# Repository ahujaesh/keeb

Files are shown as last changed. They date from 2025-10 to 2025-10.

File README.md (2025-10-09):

Eshaan's Split Keeb!

A seed studio rp2040 based ergonomic split keyboards to make essay writing slightly less boring! It has 50 keys (alphabet [26], numbers [10], ;,./ [4], two shifts [2], two ctrls [2], win key [1], two space keys [2], and two keys i plan to remap once the board comes in depending on what i fell like im missing), a built in USB hub, and a haptic motor!

PCB ([kicad](/keeb), [gerbers](/gerbers_final^2.zip)):
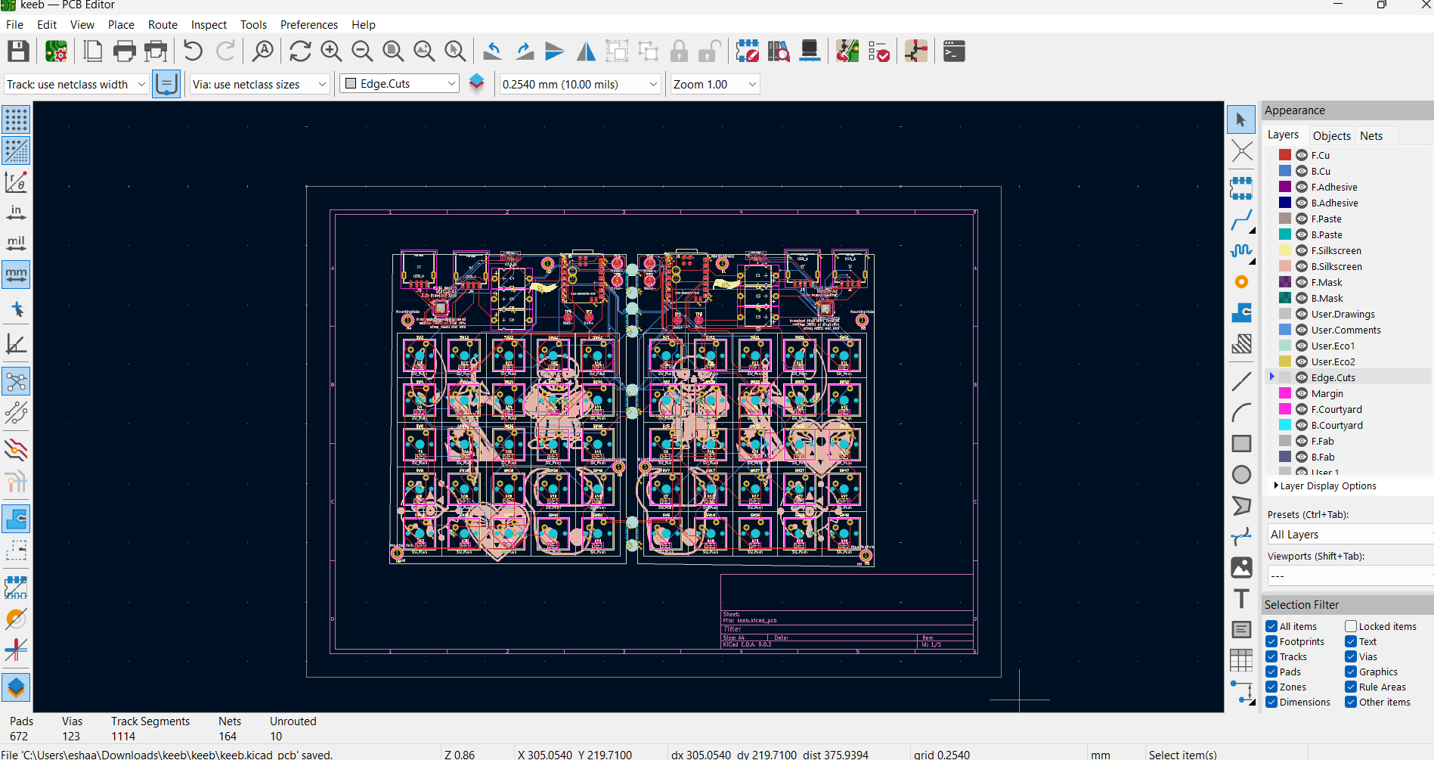
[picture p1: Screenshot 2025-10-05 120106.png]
pcb screenshot

CAD ([STEP file of assembly](/final_assembly.step), [top plate](/Top%20plate.step), [bottom plate](/Bottom%20plate.step)):
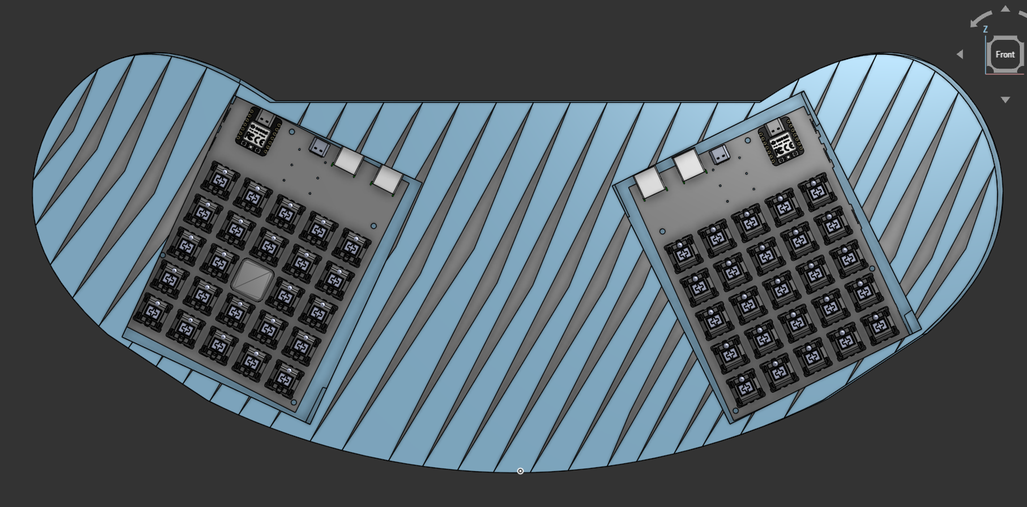
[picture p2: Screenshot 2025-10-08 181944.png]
cad screenshot

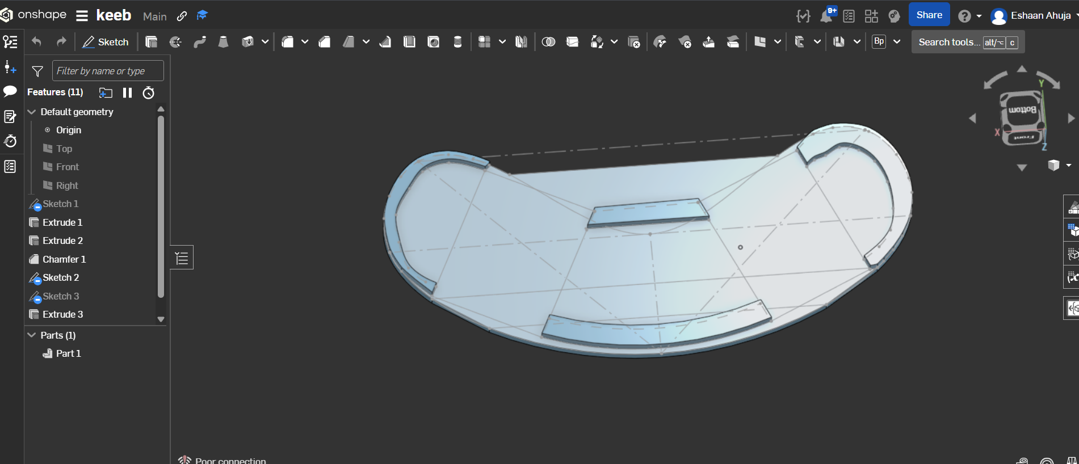
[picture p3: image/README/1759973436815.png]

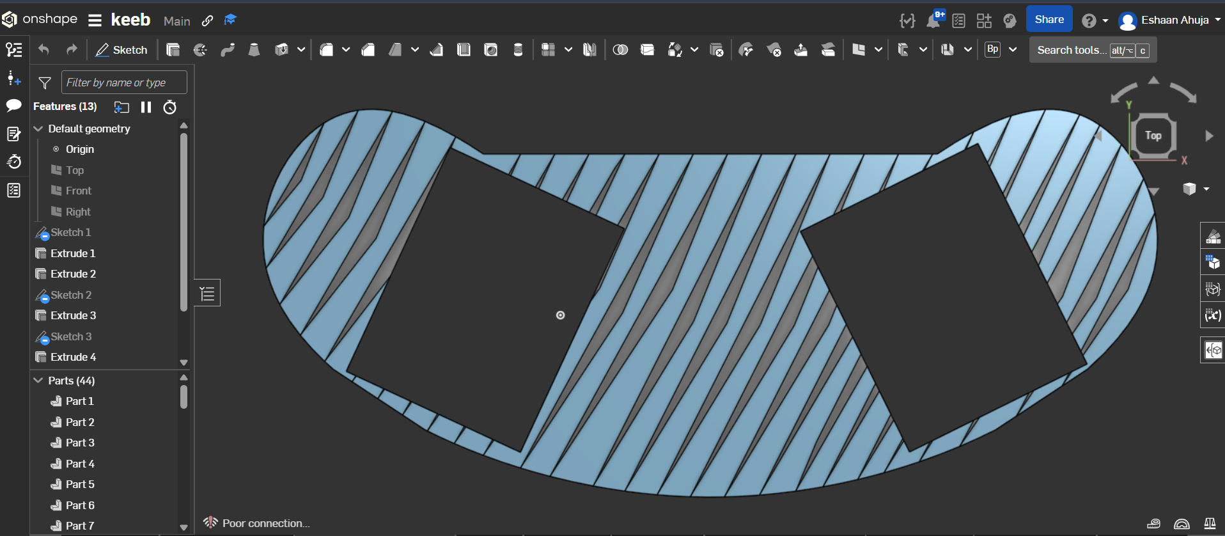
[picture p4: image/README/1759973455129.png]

Firmware [[left](/left.py), [right](/right.py)]: KMK (python), two files, one per board. Key matrix and one layer (for now, once i get the keeb i might add one more for funzies)
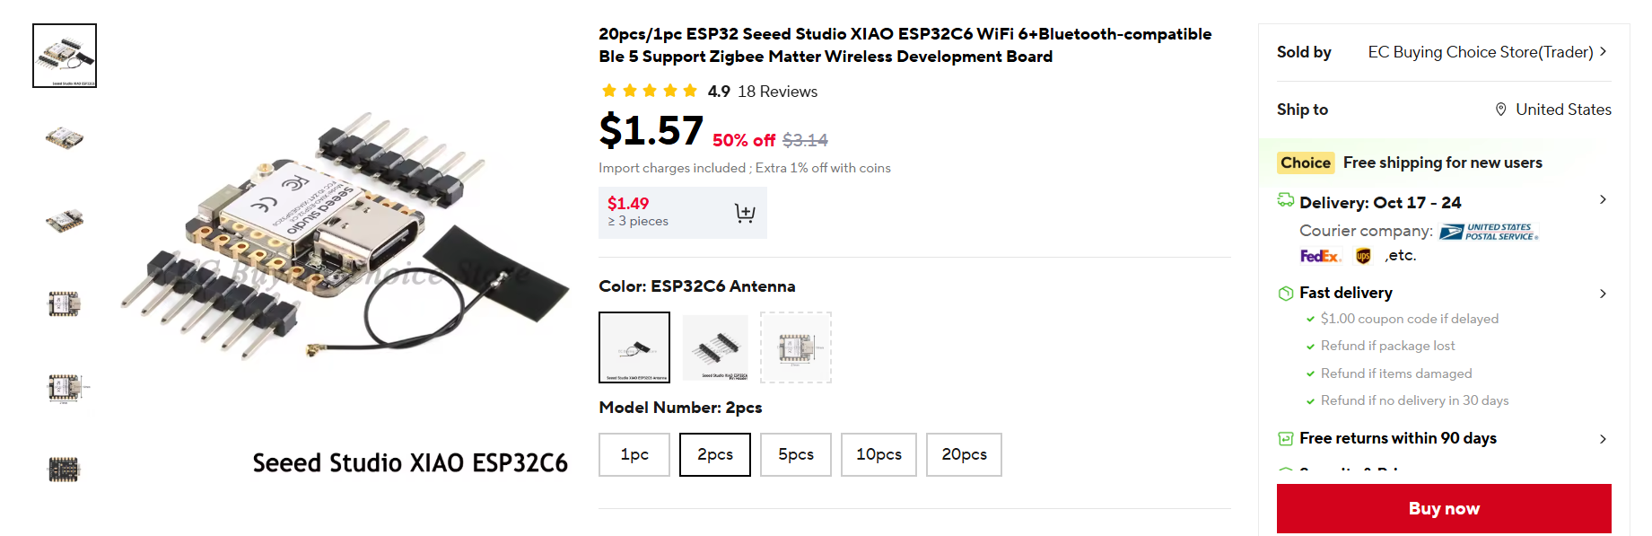
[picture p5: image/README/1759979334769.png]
Aliexpress screenshot 
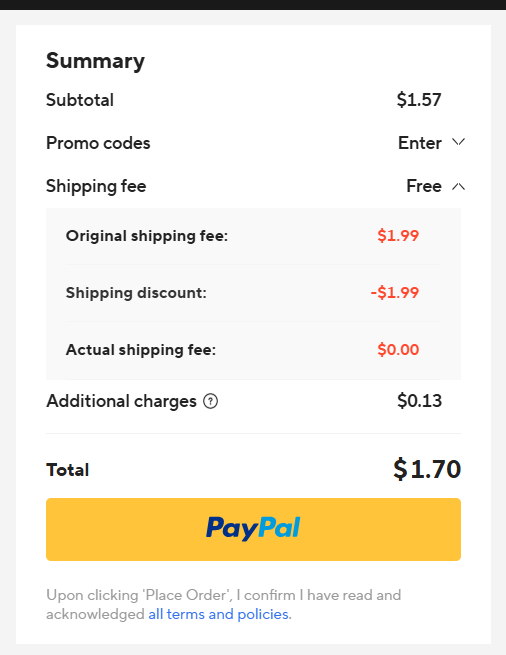
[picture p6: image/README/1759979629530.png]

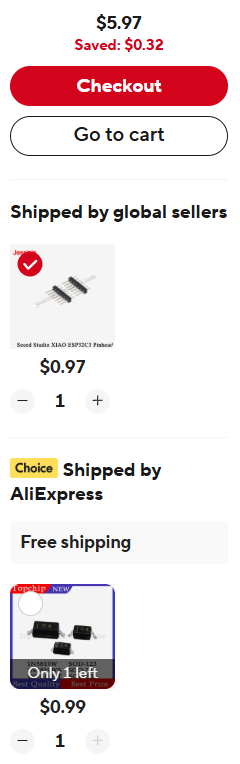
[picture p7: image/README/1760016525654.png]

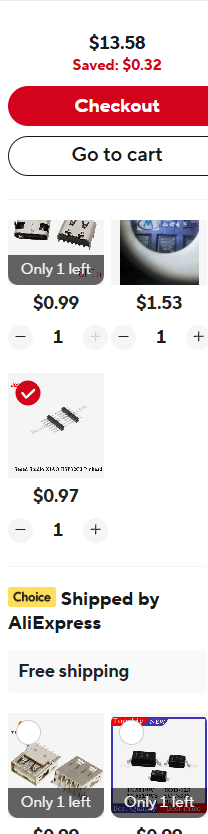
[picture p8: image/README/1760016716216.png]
aliexpress screenshot with everything: 
amazon switches screenshot

All for the low price of 54.73 USD :crying emoji:
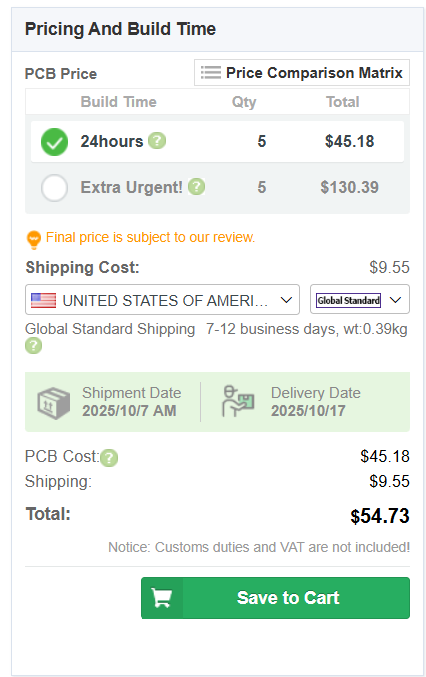
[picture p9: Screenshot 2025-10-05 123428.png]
pcbway quote


AND it has a built in USB hub for PIZZAZ

Using the USB2512_AEZG chip, I take an input of USBC and split it into two USBA ports (bc no laptop nowadays comes with USBA ports smh)
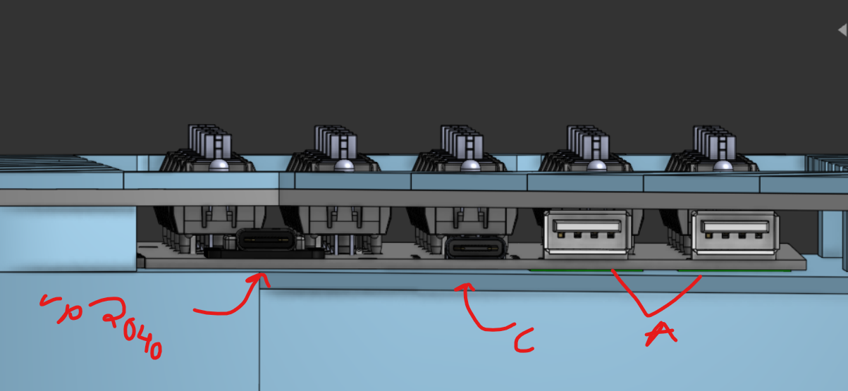
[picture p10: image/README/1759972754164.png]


This keyboard has a 5x5 matrix on both sides, positioned at a comfortable 27 degrees so that my wrists don't cramp up while typing! It uses MX switches (the cheapest ones I could find lmao) (not hot swappable unfortunately), and 3d printed keycaps (save hack club some money lmao)

Finally, it has a built in haptic motor soldered onto the pcb to provide a better typing experience :) I couldnt find a cad model but its a really small motor that sits under the USBA ports and gets attached to the test points on the side of the seed studio

Note: switches are soldered on, I am printing the top and bottom plate, as well as the keycaps. for more info, see the [BOM](/bom.csv)

I had a lot of fun playing with splines etc whilst doing this project! Thanks hack club for the opportunity

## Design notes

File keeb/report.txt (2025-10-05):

Plotted to 'C:\Users\eshaa\Downloads\keeb\keeb-F_Cu.gbr'.
Plotted to 'C:\Users\eshaa\Downloads\keeb\keeb-B_Cu.gbr'.
Plotted to 'C:\Users\eshaa\Downloads\keeb\keeb-F_Paste.gbr'.
Plotted to 'C:\Users\eshaa\Downloads\keeb\keeb-B_Paste.gbr'.
Plotted to 'C:\Users\eshaa\Downloads\keeb\keeb-F_Silkscreen.gbr'.
Plotted to 'C:\Users\eshaa\Downloads\keeb\keeb-B_Silkscreen.gbr'.
Plotted to 'C:\Users\eshaa\Downloads\keeb\keeb-F_Mask.gbr'.
Plotted to 'C:\Users\eshaa\Downloads\keeb\keeb-B_Mask.gbr'.
Plotted to 'C:\Users\eshaa\Downloads\keeb\keeb-Edge_Cuts.gbr'.
Created Gerber job file 'C:\Users\eshaa\Downloads\keeb\keeb-job.gbrjob'.
Info: Done.
Info: Done.

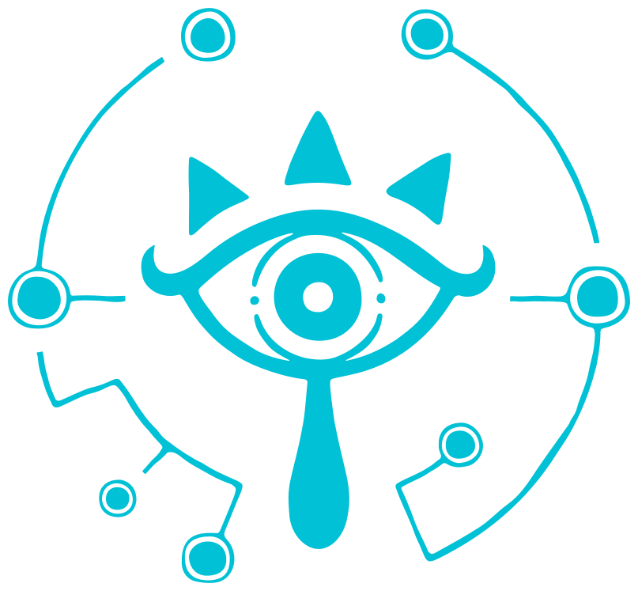
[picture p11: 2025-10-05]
images/Das_Shiekah_Auge_BoTW.webp

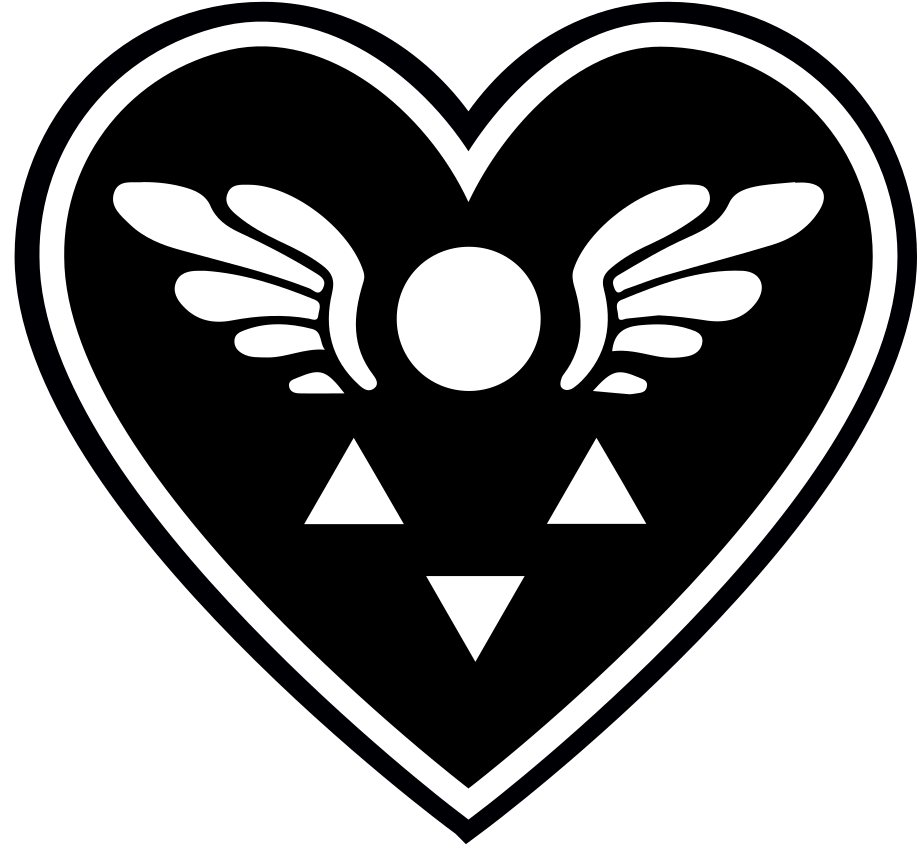
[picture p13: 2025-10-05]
images/v1180jzwulx11.png

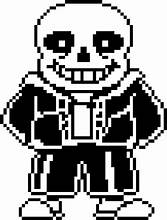
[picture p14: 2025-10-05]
images/OIP2.jpeg

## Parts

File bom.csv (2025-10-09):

name | costs (USD) | notes
pcb | 54.73 | see screenshot in readme
motors | 0 | for haptics and self sourced (i already have some)
seed studio xiao x2 (one per side) | 1.7 | see readme for screenshots from aliexpress
keycaps | 0 | 3d printed by me
switches | 25 | $5 per 10 = 25 for 50 keycaps; amazon
capacitors | 0 | self sourced (I already have them)
diodes | 5.97 | aliexpress shipping is expensive
usb2512aezg chip | 7 | to power the usb hub; see screenshot in readme; sourced from aliexpress
usba port x4 | 1 | see screenshot in readme; sourced from aliexpress
usbc port x2 | 1 | aliexpress
3d printed parts | 0 | I'm printing everything myself
TOTAL | 96.4 USD | thank you!

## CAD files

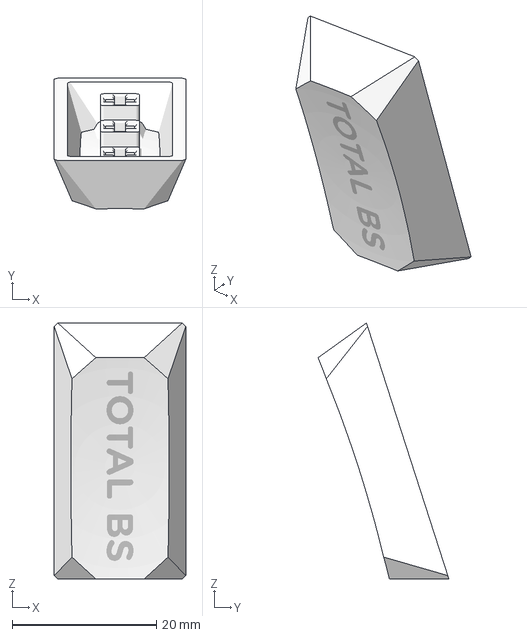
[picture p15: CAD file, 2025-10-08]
misc/complete-cherry-mx-stem-keycap-set-optimized-for-3d-printing-gem-profile-multi-material-model_files/2U_TOTALBS.3mf
18.2 x 18.1 x 35.5 mm

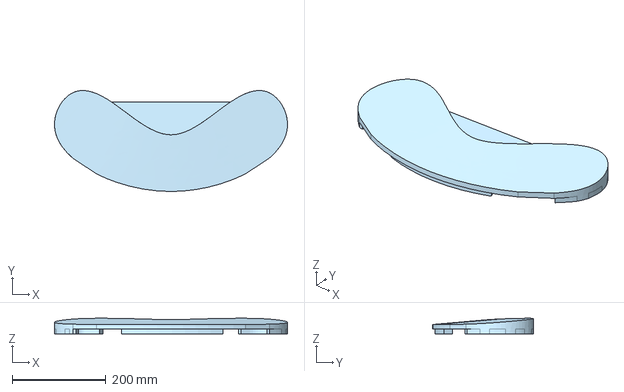
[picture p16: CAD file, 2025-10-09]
Bottom plate.step
498.1 x 215.9 x 33.3 mm

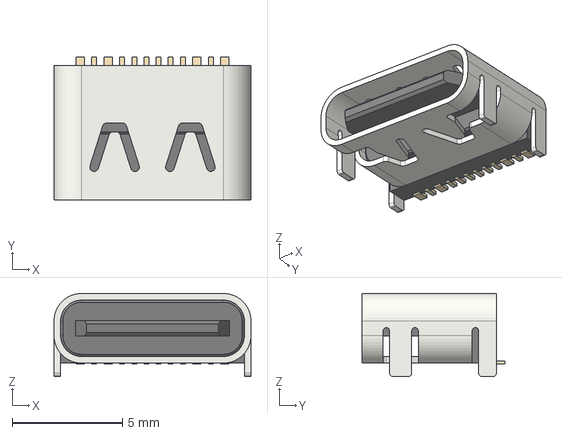
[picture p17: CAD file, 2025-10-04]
marbastlib-main/marbastlib-main/3dmodels/CON_TYPE-C-31-M-23.step
8.94 x 6.50 x 3.77 mm

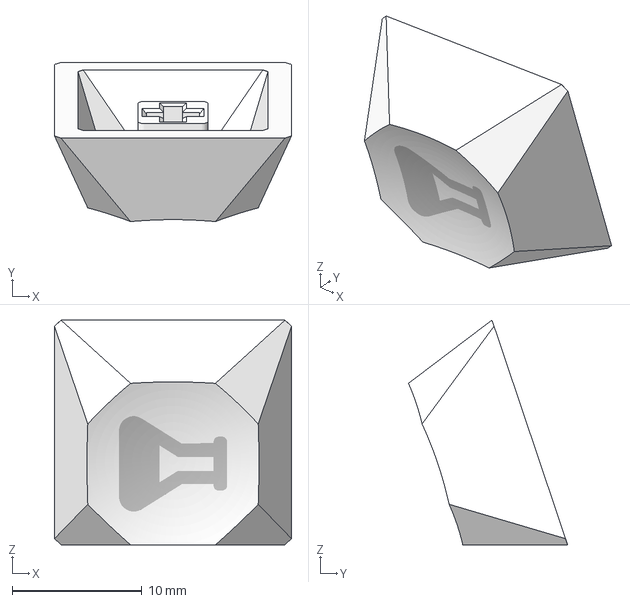
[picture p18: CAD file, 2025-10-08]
misc/complete-cherry-mx-stem-keycap-set-optimized-for-3d-printing-gem-profile-multi-material-model_files/flask.3mf
18.2 x 12.3 x 17.3 mm

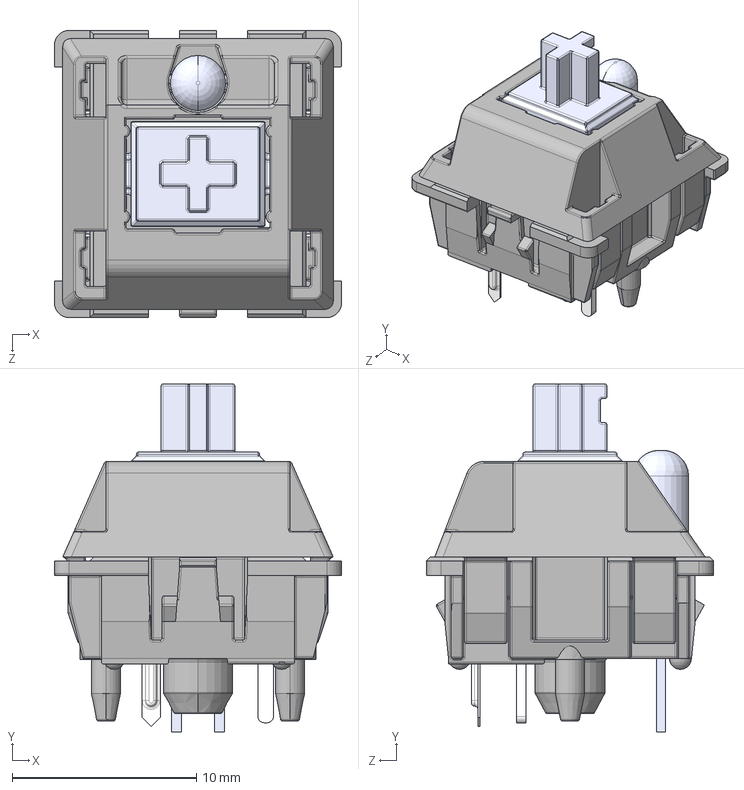
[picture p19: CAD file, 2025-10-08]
misc/MX .STEP
15.6 x 18.9 x 15.6 mm
MX 轴 按键′_ü___¨1
MX 轴 轴体áì_¨￠¨__
MX粣 拸簽LEDLEDLED
MX轴 轴体 底部 μ×2__默认_á2____è_
针脚___默认__è_

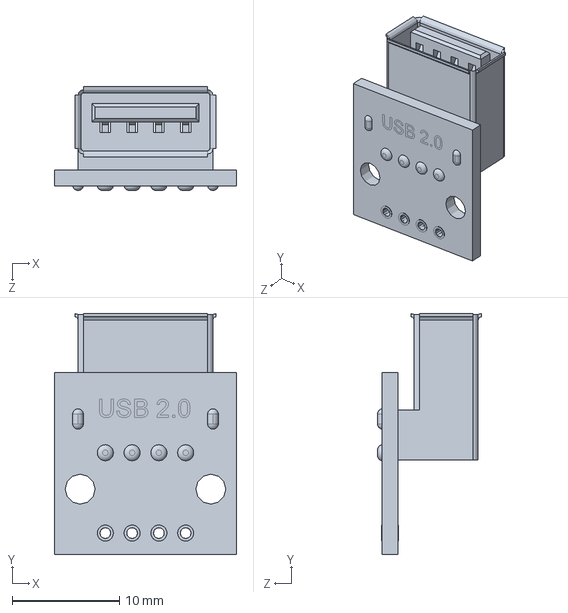
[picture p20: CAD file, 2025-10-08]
misc/usb-a-female-2.snapshot.1/модуль USB A.SLDPRT
17.0 x 22.5 x 9.70 mm

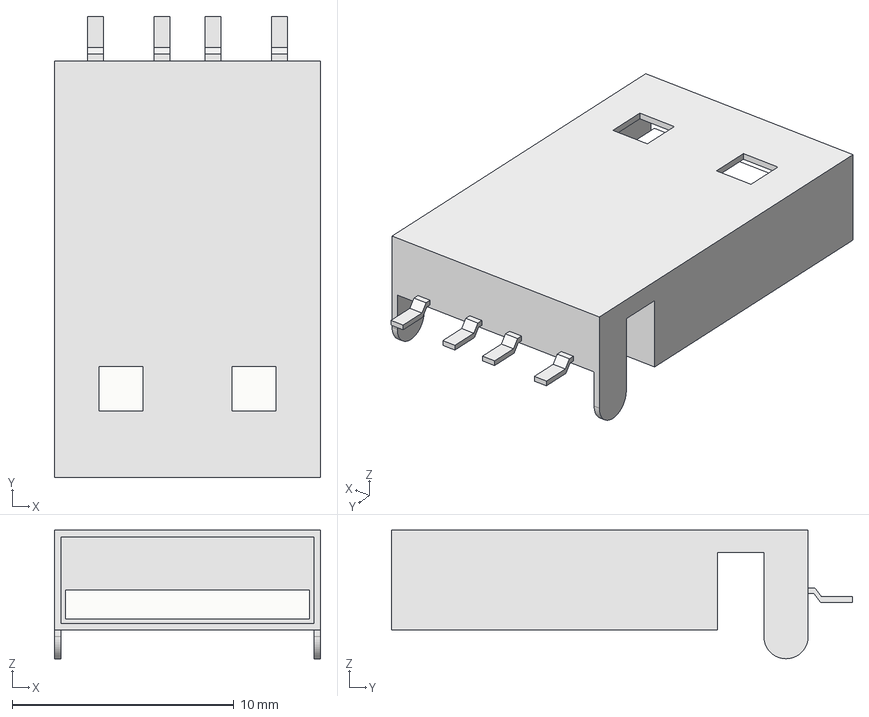
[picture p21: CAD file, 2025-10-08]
misc/usb-type-a-connector-2.snapshot.1/USB Type A.step
12.0 x 20.8 x 5.80 mm

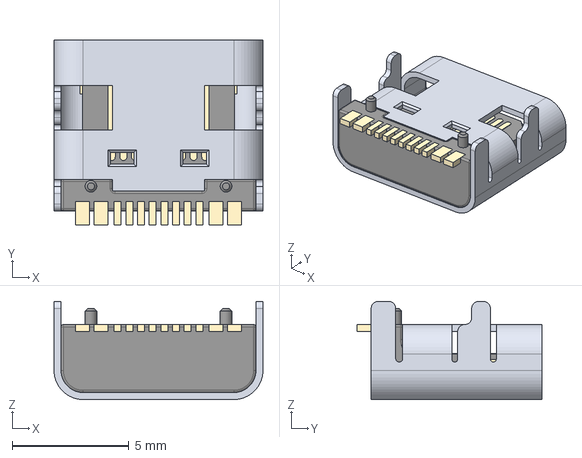
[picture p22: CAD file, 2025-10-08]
misc/usb-type-c-port-2.snapshot.1/USB Type C PoRT.step
8.94 x 7.90 x 4.20 mm

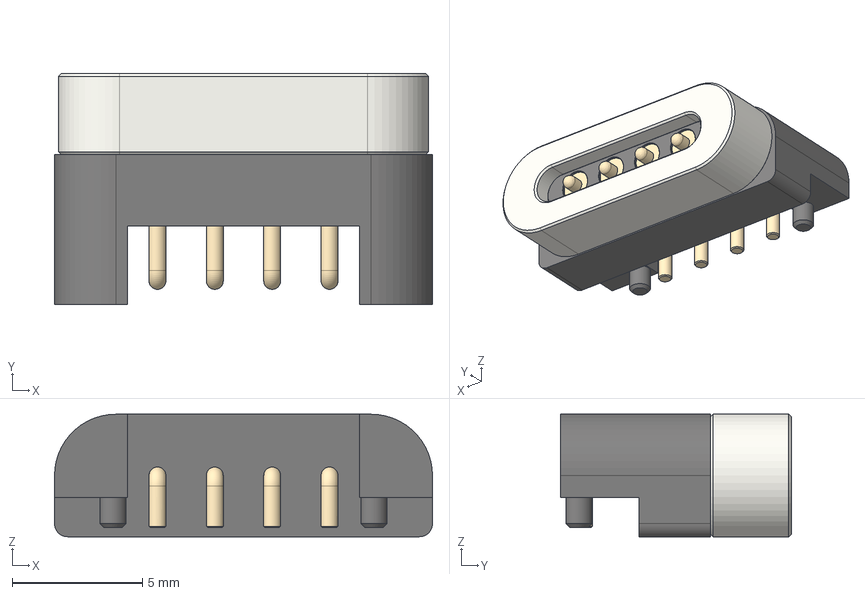
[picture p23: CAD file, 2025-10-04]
marbastlib-main/marbastlib-main/3dmodels/CON_HytePro_M411P_Receptacle_1x04.step
14.5 x 8.85 x 4.70 mm
Magnetic Connector Female - MiddlePart
Magnetic Connector Female-tip_Standard
Magnetic Connector Female v2 - MountingPart

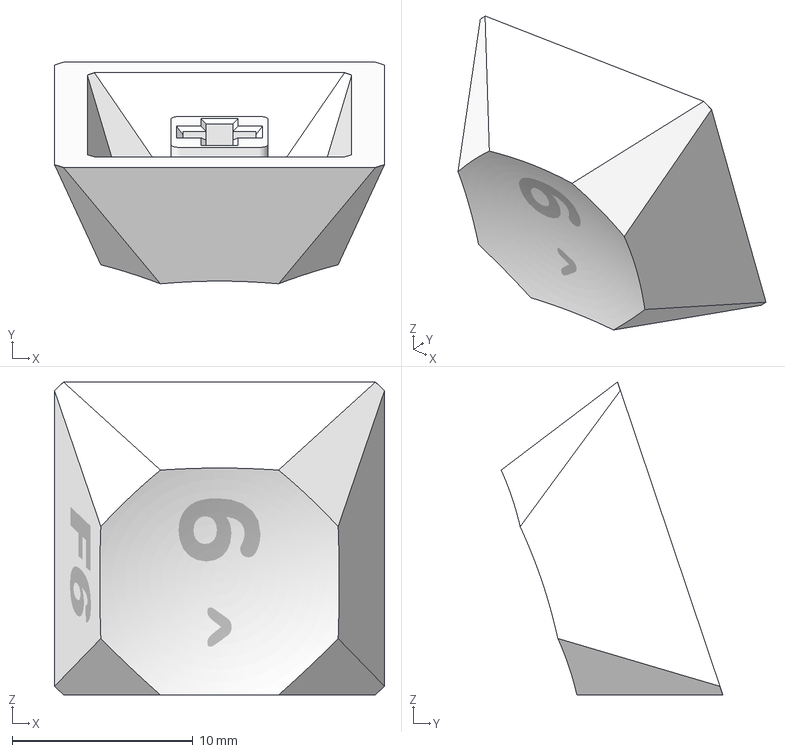
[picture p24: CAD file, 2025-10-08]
misc/complete-cherry-mx-stem-keycap-set-optimized-for-3d-printing-gem-profile-multi-material-model_files/6_F6.3mf
18.2 x 12.3 x 17.3 mm

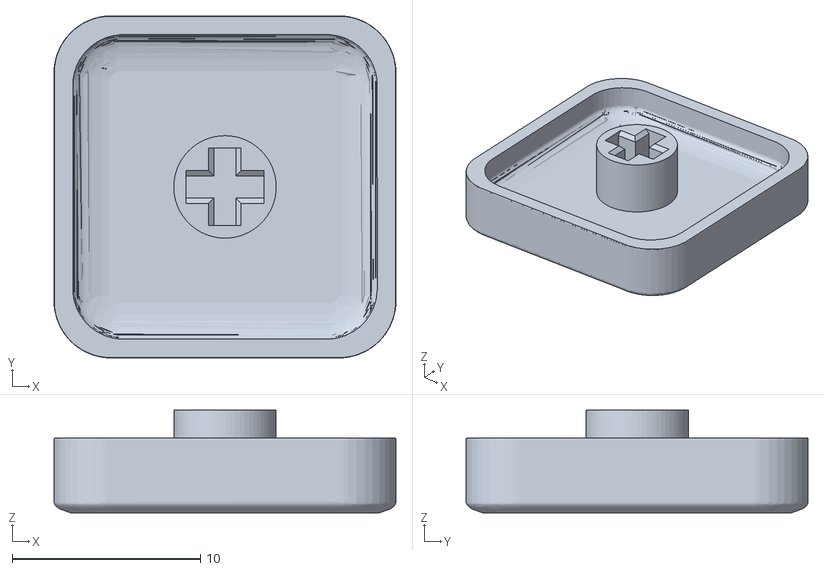
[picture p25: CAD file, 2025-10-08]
misc/Keycap 1U Low Profile.stl
18.2 x 18.2 x 5.48

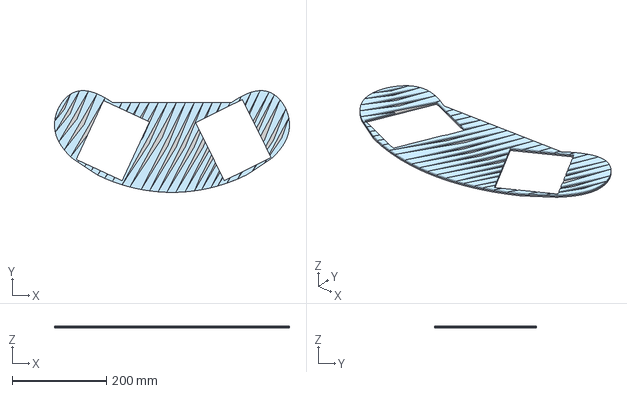
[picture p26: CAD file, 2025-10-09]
Top plate.step
498.2 x 215.8 x 5.08 mm

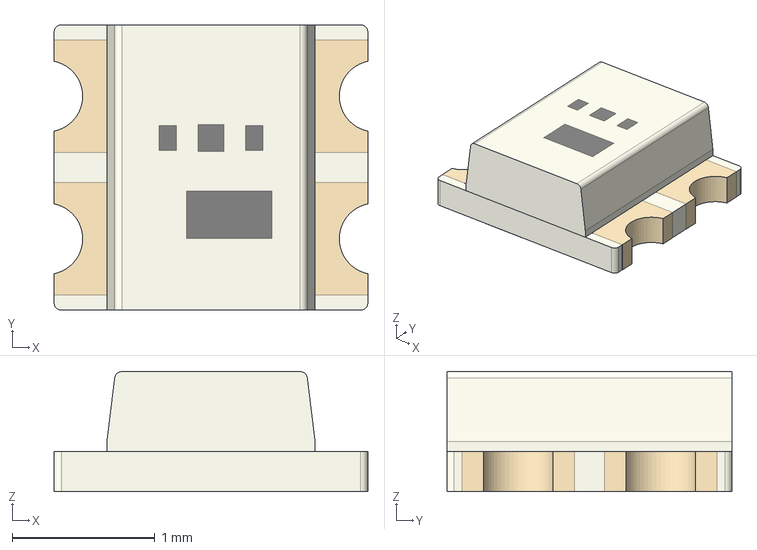
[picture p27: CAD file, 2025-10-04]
marbastlib-main/marbastlib-main/3dmodels/LED_WS2812_2020.step
2.20 x 2.00 x 0.842 mm

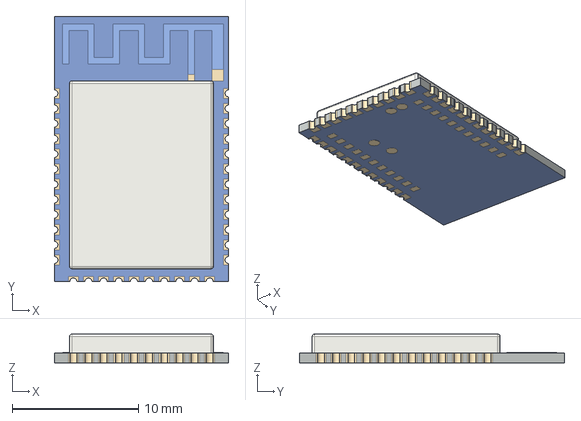
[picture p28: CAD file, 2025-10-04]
marbastlib-main/marbastlib-main/3dmodels/moko_mk08a_nRF52840.step
13.8 x 21.0 x 2.29 mm

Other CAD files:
misc/complete-cherry-mx-stem-keycap-set-optimized-for-3d-printing-gem-profile-multi-material-model_files/equal.3mf
misc/complete-cherry-mx-stem-keycap-set-optimized-for-3d-printing-gem-profile-multi-material-model_files/2.25U_ShiftyShiftL.3mf
marbastlib-main/marbastlib-main/3dmodels/RP2040-Matrix.step
misc/complete-cherry-mx-stem-keycap-set-optimized-for-3d-printing-gem-profile-multi-material-model_files/numlock.3mf
marbastlib-main/marbastlib-main/3dmodels/CON_2082940020.step
marbastlib-main/marbastlib-main/3dmodels/CON_2082940030.step
marbastlib-main/marbastlib-main/3dmodels/CON_2082940040.step
marbastlib-main/marbastlib-main/3dmodels/CON_2082940050.step
marbastlib-main/marbastlib-main/3dmodels/CON_2121340002.step
marbastlib-main/marbastlib-main/3dmodels/CON_2121340003.step
marbastlib-main/marbastlib-main/3dmodels/CON_2121340004.step
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

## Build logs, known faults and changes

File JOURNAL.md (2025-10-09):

<!--
  ===================    !!READ THIS NOTICE!!   ====================
  DO NOT edit this file manually. Your changes WILL BE OVERWRITTEN!
  This journal is auto generated and updated by Hack Club Blueprint.
  To edit this file, please edit your journal entries on Blueprint.
  ==================================================================
-->

This is my journal of the design and building process of **split keeb!**.  
You can view this journal in more detail on **Hack Club Blueprint** [here](https://blueprint.hackclub.com/projects/107).

## 10/4/2025 5 PM - finished the schematic  



Set up the project, added the key matrix and seedstudio, and got them added to the schematic [1hr]
Researched how to make a USB hub, how the USB protocol worked, chose [this](https://www.microchip.com/en-us/product/USB2512) IC, added a USB-C upstream, and two USB-A downstream [1hr 45min]
Had a lot of fun starting a larger project: my only other real experience with PCBs was the Macropad from Highway (which was also fun). I'm now looking to work on routing, then CAD  

## 10/4/2025 6 PM - assigned footprints, fixed electrical rules checker errors  



I fixed the ERC errors by adding no connect flags to the unused pins, I assigned the footprints for all the components, and initialized the PCB with all the components. I also forgot to add the mounting holes and mousebites to the last commit, so I added those as well. Next commit will be routing all the components, then full CAD, then firmware (looking to use KMK as that's what I used for the Macropad)

Note: Game of Thrones OST is great for PCB work :), Celeste is good too (used that last commit)
ps. I always include the Windows Stopwatch screenshot as proof of how long I spent working on each commit  

## 10/4/2025 10 PM - worked on routing the pcb  


This took much longer than I expected, but it was lots of fun. I started by organising all the components on the PCB, which took about an hour on its own. I then routed the processors on top for about an hour, and, lastly, routed the keys for the last hour. All I have left to route are the ~20 traces going between the halves of the board. I'm quite happy I was able to keep this to two layers. I thought I'd have to bump it up to three for the areas around the USB hub's IC. It's messy, but I think it'll work

 P.S. Skyward Sword music is great too
can't wait to type on the new keeb

## 10/5/2025 - finished routing, added the back Silkscreen, fixed DRC  


I finished the leftover routing, added some images to the back silkscreen, and went through the DRC errors. There are still some problems with the USB-C port's clearance, but otherwise, the PCB is almost done. I'll try to get the Cad and FW done this week so I can wrap up and submit on Sat. PCB way says ~54$ for the pcb.



## 10/7/2025 - fixed pcb errors  

PCBway sent some feedback on the PCB, so I went ahead and incorporated that into the design

They wanted me to move the USBC pads further from the edge of the board and to check the clearances between the pads of the IC. I've made changes and resent the Gerbers. I'll finish up the programming and CAD, then submit :)  

## 10/8/2025 - worked on CAD for the case  

this took way too long lmao
I worked on this throughout the school day (thanks to my Spanish/bio teachers, the goat)
Added a cool design to the top, picked switches, 5 degree slope, and make it look cool
Also, onshape bugged out when I imported my PCB bc for some reason, each copper trace was its own object [insert crying emoji here]
played Silksong OST while working today :)
This is the top plate:

this is the full cad

This is the timer lmao  

## 10/9/2025 12 AM - firmware :)  

The firmware went a lot faster this time, now that I have experience from my Macropad, but the longest time will be debugging this thing once it arrives (that took so long on the Macropad)
I made two files, left and right.py, in KMK that I can flash to the two seed studios
Each file has a hardcoded map from the rows/collumns to the keys
Also found a missing via in the PCB while looking at it, so I fixed that lmao


## 10/9/2025 1 AM - wrote the readme and organised the files  


I went ahead and wrote the README, including links to the CAD models, PCBs, etc., alongside a description of what's special about this keyboard and how the firmware works (KMK). Short devlog today. Listened to music from FF and Ori and the Will of the Wisps :)


## 10/9/2025 1 PM - finished BOM and wrapped up project  

I went through and reviewed the pcb, reread the FW, and found all my parts on aliexpress, and wrote the final BOM. The PCBWAY quote was also approved.
aliexpress screenshot with everything:

Total is under 100!
(the pcb was verry expensive so i opted to 3d print keycaps and self source some parts from things i already had to reduce cost)

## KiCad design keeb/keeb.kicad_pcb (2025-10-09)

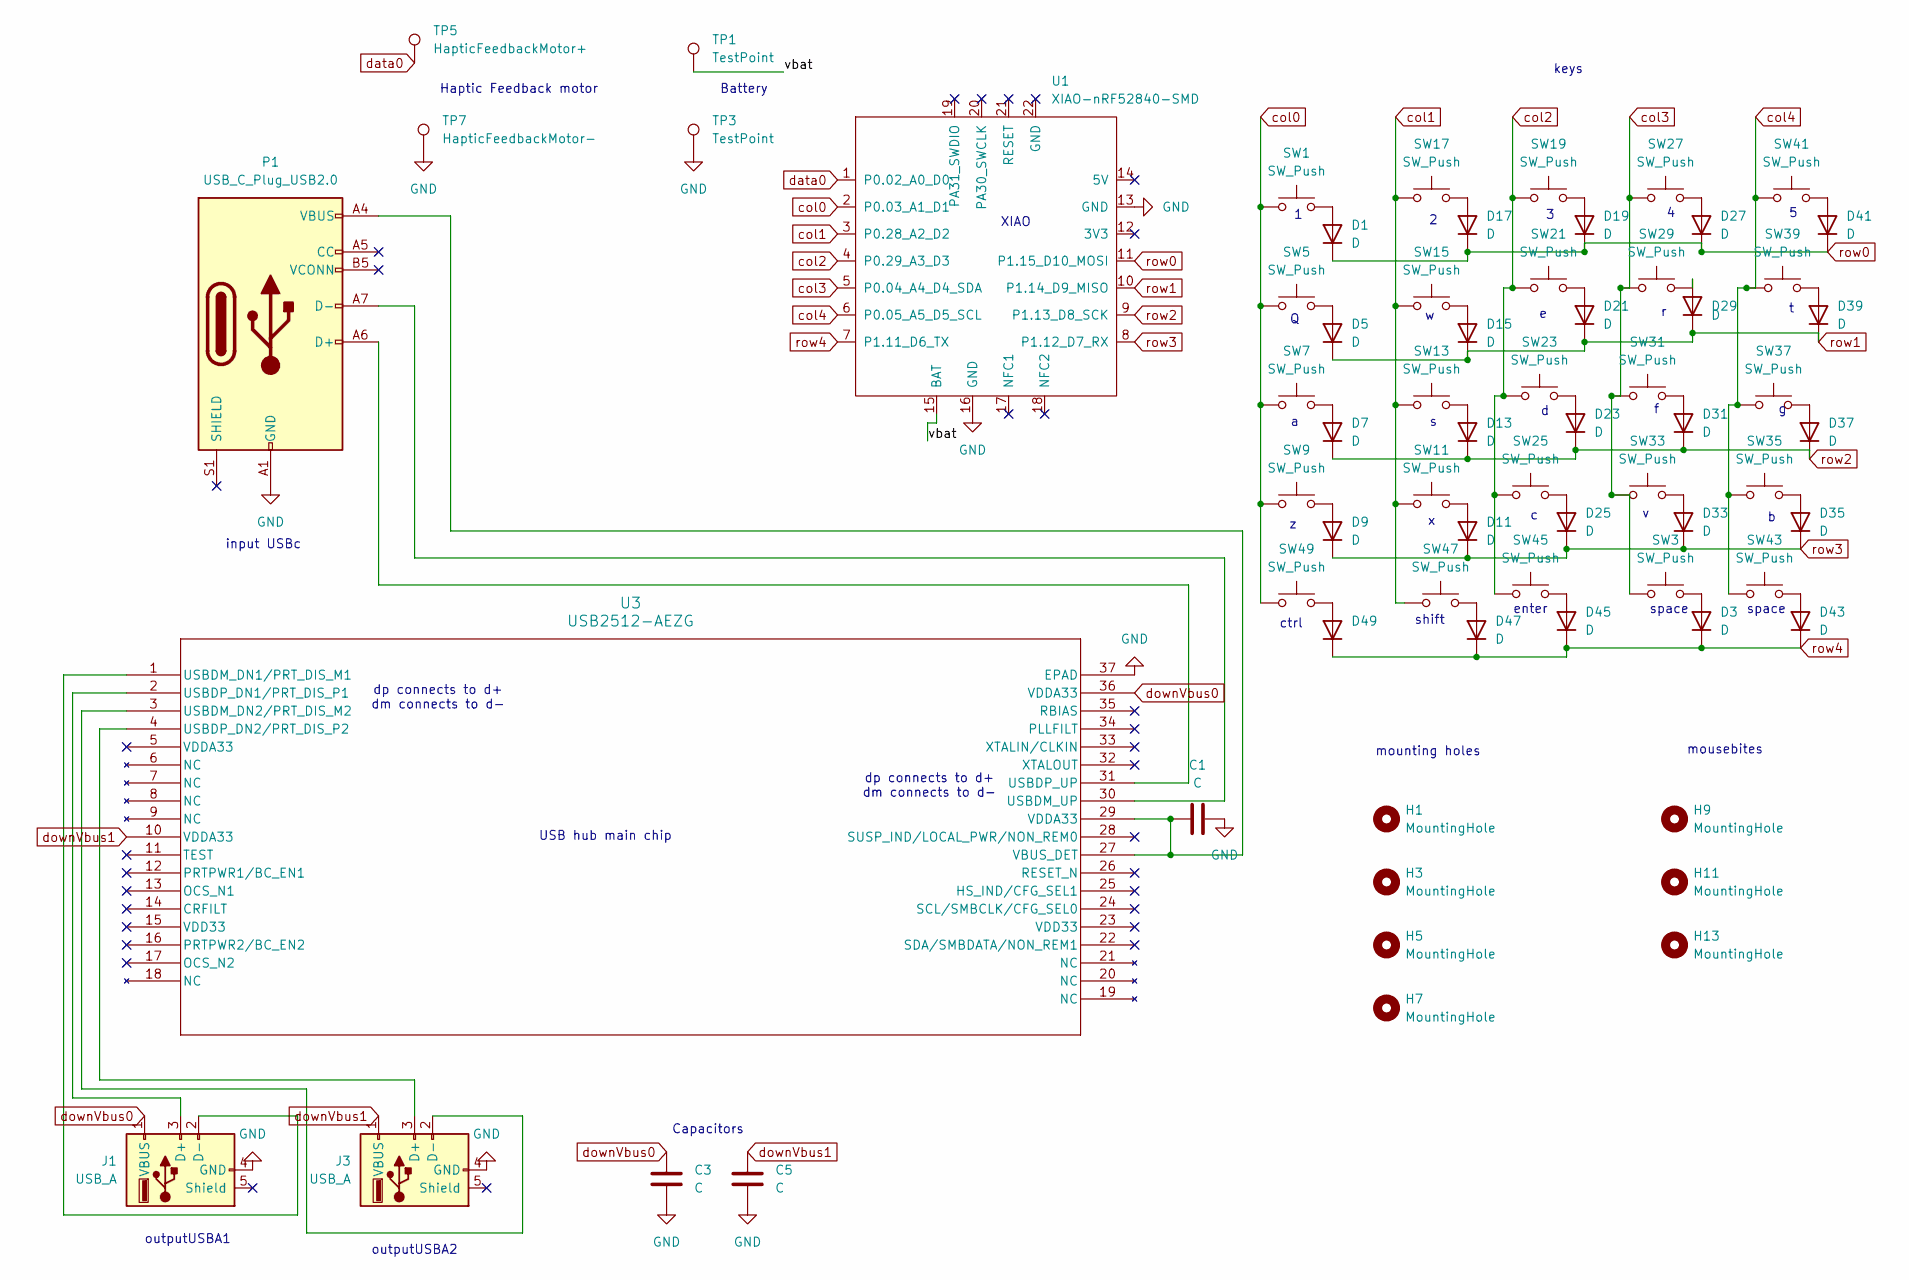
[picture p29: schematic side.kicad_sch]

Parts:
C1, C3, C5: C; CP_Axial_L11.0mm_D8.0mm_P15.00mm_Horizontal
D1, D3, D5, D7, D9, D11, D13, D15, D17, D19, D21, D23, D25, D27, D29, D31, D33, D35, D37, D39, D41, D43, D45, D47, D49: D; D_SOD-123
H1, H3, H5, H7: MountingHole; TestPoint_Loop_D3.80mm_Drill2.8mm
H9, H11, H13: MountingHole; mouse-bite-5mm-slot
J1, J3: USB_A; USB_A_Receptacle_GCT_USB1046
P1: USB_C_Plug_USB2.0; USB_C_Plug_Molex_105444
SW1, SW3, SW5, SW7, SW9, SW11, SW13, SW15, SW17, SW19, SW21, SW23, SW25, SW27, SW29, SW31, SW33, SW35, SW37, SW39, SW41, SW43, SW45, SW47, SW49: SW_Push; SW_Cherry_MX_1.00u_PCB
TP1, TP3: TestPoint; TestPoint_Pad_D3.0mm
TP5: HapticFeedbackMotor+; TestPoint_Pad_D4.0mm
TP7: HapticFeedbackMotor-; TestPoint_Pad_D4.0mm
U1: XIAO-nRF52840-SMD; modified-XIAO-nRF52840-SMD
U3: USB2512-AEZG; QFN36_6X6MC_MCH

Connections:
/left/vbat: TP1.1, U1.15 (BAT)
GND: C1.2, C3.2, C5.2, J1.4 (GND), J3.4 (GND), P1.A1 (GND), P1.A12 (GND), P1.B1 (GND), P1.B12 (GND), TP3.1, TP7.1, U1.13 (GND), U1.16 (GND), U3.37 (EPAD); also elsewhere on the board
unnamed: D1.2 (A), SW1.2
unnamed: D3.2 (A), SW3.2
unnamed: D5.2 (A), SW5.2
unnamed: D7.2 (A), SW7.2
unnamed: D9.2 (A), SW9.2
unnamed: D11.2 (A), SW11.2
unnamed: D13.2 (A), SW13.2
unnamed: D15.2 (A), SW15.2
unnamed: D17.2 (A), SW17.2
unnamed: D19.2 (A), SW19.2
unnamed: D21.2 (A), SW21.2
unnamed: D23.2 (A), SW23.2
unnamed: D25.2 (A), SW25.2
unnamed: D27.2 (A), SW27.2
unnamed: D29.2 (A), SW29.2
unnamed: D31.2 (A), SW31.2
unnamed: D33.2 (A), SW33.2
unnamed: D35.2 (A), SW35.2
unnamed: D37.2 (A), SW37.2
unnamed: D39.2 (A), SW39.2
unnamed: D41.2 (A), SW41.2
unnamed: D43.2 (A), SW43.2
unnamed: D45.2 (A), SW45.2
unnamed: D47.2 (A), SW47.2
unnamed: D49.2 (A), SW49.2
unnamed: J1.3 (D+), U3.2 (USBDP_DN1/PRT_DIS_P1)
unnamed: J1.2 (D-), U3.1 (USBDM_DN1/PRT_DIS_M1)
unnamed: J3.3 (D+), U3.4 (USBDP_DN2/PRT_DIS_P2)
unnamed: J3.2 (D-), U3.3 (USBDM_DN2/PRT_DIS_M2)
unnamed: P1.A6 (D+), U3.31 (USBDP_UP)
unnamed: P1.A7 (D-), U3.30 (USBDM_UP)
unnamed: C1.1, P1.A4 (VBUS), P1.A9 (VBUS), P1.B4 (VBUS), P1.B9 (VBUS), U3.27 (VBUS_DET), U3.29 (VDDA33)
col0: SW1.1, SW5.1, SW7.1, SW9.1, SW49.1, U1.2 (P0.03_A1_D1); also elsewhere on the board
col1: SW11.1, SW13.1, SW15.1, SW17.1, SW47.1, U1.3 (P0.28_A2_D2); also elsewhere on the board
col2: SW19.1, SW21.1, SW23.1, SW25.1, SW45.1, U1.4 (P0.29_A3_D3); also elsewhere on the board
col3: SW3.1, SW27.1, SW29.1, SW31.1, SW33.1, U1.5 (P0.04_A4_D4_SDA); also elsewhere on the board
col4: SW35.1, SW37.1, SW39.1, SW41.1, SW43.1, U1.6 (P0.05_A5_D5_SCL); also elsewhere on the board
data0: TP5.1, U1.1 (P0.02_A0_D0); also elsewhere on the board
downVbus0: C3.1, J1.1 (VBUS), U3.36 (VDDA33); also elsewhere on the board
downVbus1: C5.1, J3.1 (VBUS), U3.10 (VDDA33); also elsewhere on the board
row0: D1.1 (K), D17.1 (K), D19.1 (K), D27.1 (K), D41.1 (K), U1.11 (P1.15_D10_MOSI); also elsewhere on the board
row1: D5.1 (K), D15.1 (K), D21.1 (K), D29.1 (K), D39.1 (K), U1.10 (P1.14_D9_MISO); also elsewhere on the board
row2: D7.1 (K), D13.1 (K), D23.1 (K), D31.1 (K), D37.1 (K), U1.9 (P1.13_D8_SCK); also elsewhere on the board
row3: D9.1 (K), D11.1 (K), D25.1 (K), D33.1 (K), D35.1 (K), U1.8 (P1.12_D7_RX); also elsewhere on the board
row4: D3.1 (K), D43.1 (K), D45.1 (K), D47.1 (K), D49.1 (K), U1.7 (P1.11_D6_TX); also elsewhere on the board

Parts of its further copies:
C2, C4, C6: C; CP_Axial_L11.0mm_D8.0mm_P15.00mm_Horizontal
D2, D4, D6, D8, D10, D12, D14, D16, D18, D20, D22, D24, D26, D28, D30, D32, D34, D36, D38, D40, D42, D44, D46, D48, D50: D; D_SOD-123
H2, H4, H6, H8: MountingHole; TestPoint_Loop_D3.80mm_Drill2.8mm
H10, H12, H14: MountingHole; mouse-bite-5mm-slot
J2, J4: USB_A; USB_A_Receptacle_GCT_USB1046
SW2, SW4, SW6, SW8, SW10, SW12, SW14, SW16, SW18, SW20, SW22, SW24, SW26, SW28, SW30, SW32, SW34, SW36, SW38, SW40, SW42, SW44, SW46, SW48, SW50: SW_Push; SW_Cherry_MX_1.00u_PCB
U2: XIAO-nRF52840-SMD; modified-XIAO-nRF52840-SMD
U4: USB2512-AEZG; QFN36_6X6MC_MCH

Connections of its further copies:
/right/vbat: U2.15 (BAT); also elsewhere on the board
GND: C2.2, C4.2, C6.2, J2.4 (GND), J4.4 (GND), U2.13 (GND), U2.16 (GND), U4.37 (EPAD); also elsewhere on the board
unnamed: D2.2 (A), SW2.2
unnamed: D4.2 (A), SW4.2
unnamed: D6.2 (A), SW6.2
unnamed: D8.2 (A), SW8.2
unnamed: D10.2 (A), SW10.2
unnamed: D12.2 (A), SW12.2
unnamed: D14.2 (A), SW14.2
unnamed: D16.2 (A), SW16.2
unnamed: D18.2 (A), SW18.2
unnamed: D20.2 (A), SW20.2
unnamed: D22.2 (A), SW22.2
unnamed: D24.2 (A), SW24.2
unnamed: D26.2 (A), SW26.2
unnamed: D28.2 (A), SW28.2
unnamed: D30.2 (A), SW30.2
unnamed: D32.2 (A), SW32.2
unnamed: D34.2 (A), SW34.2
unnamed: D36.2 (A), SW36.2
unnamed: D38.2 (A), SW38.2
unnamed: D40.2 (A), SW40.2
unnamed: D42.2 (A), SW42.2
unnamed: D44.2 (A), SW44.2
unnamed: D46.2 (A), SW46.2
unnamed: D48.2 (A), SW48.2
unnamed: D50.2 (A), SW50.2
unnamed: J2.3 (D+), U4.2 (USBDP_DN1/PRT_DIS_P1)
unnamed: J2.2 (D-), U4.1 (USBDM_DN1/PRT_DIS_M1)
unnamed: J4.3 (D+), U4.4 (USBDP_DN2/PRT_DIS_P2)
unnamed: J4.2 (D-), U4.3 (USBDM_DN2/PRT_DIS_M2)
unnamed 63: U4.31 (USBDP_UP); also elsewhere on the board
unnamed 64: U4.30 (USBDM_UP); also elsewhere on the board
unnamed 66: C2.1, U4.27 (VBUS_DET), U4.29 (VDDA33); also elsewhere on the board
col0: SW2.1, SW6.1, SW8.1, SW10.1, SW50.1, U2.2 (P0.03_A1_D1); also elsewhere on the board
col1: SW12.1, SW14.1, SW16.1, SW18.1, SW48.1, U2.3 (P0.28_A2_D2); also elsewhere on the board
col2: SW20.1, SW22.1, SW24.1, SW26.1, SW46.1, U2.4 (P0.29_A3_D3); also elsewhere on the board
col3: SW4.1, SW28.1, SW30.1, SW32.1, SW34.1, U2.5 (P0.04_A4_D4_SDA); also elsewhere on the board
col4: SW36.1, SW38.1, SW40.1, SW42.1, SW44.1, U2.6 (P0.05_A5_D5_SCL); also elsewhere on the board
data0: U2.1 (P0.02_A0_D0); also elsewhere on the board
downVbus0: C4.1, J2.1 (VBUS), U4.36 (VDDA33); also elsewhere on the board
downVbus1: C6.1, J4.1 (VBUS), U4.10 (VDDA33); also elsewhere on the board
row0: D2.1 (K), D18.1 (K), D20.1 (K), D28.1 (K), D42.1 (K), U2.11 (P1.15_D10_MOSI); also elsewhere on the board
row1: D6.1 (K), D16.1 (K), D22.1 (K), D30.1 (K), D40.1 (K), U2.10 (P1.14_D9_MISO); also elsewhere on the board
row2: D8.1 (K), D14.1 (K), D24.1 (K), D32.1 (K), D38.1 (K), U2.9 (P1.13_D8_SCK); also elsewhere on the board
row3: D10.1 (K), D12.1 (K), D26.1 (K), D34.1 (K), D36.1 (K), U2.8 (P1.12_D7_RX); also elsewhere on the board
row4: D4.1 (K), D44.1 (K), D46.1 (K), D48.1 (K), D50.1 (K), U2.7 (P1.11_D6_TX); also elsewhere on the board

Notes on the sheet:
mousebites
dp connects to d+ dm connects to d-
enter
ctrl
input USBc
outputUSBA1
XIAO
shift
USB hub main chip
mounting holes
Battery
space
keys
Capacitors
outputUSBA2
Haptic Feedback motor

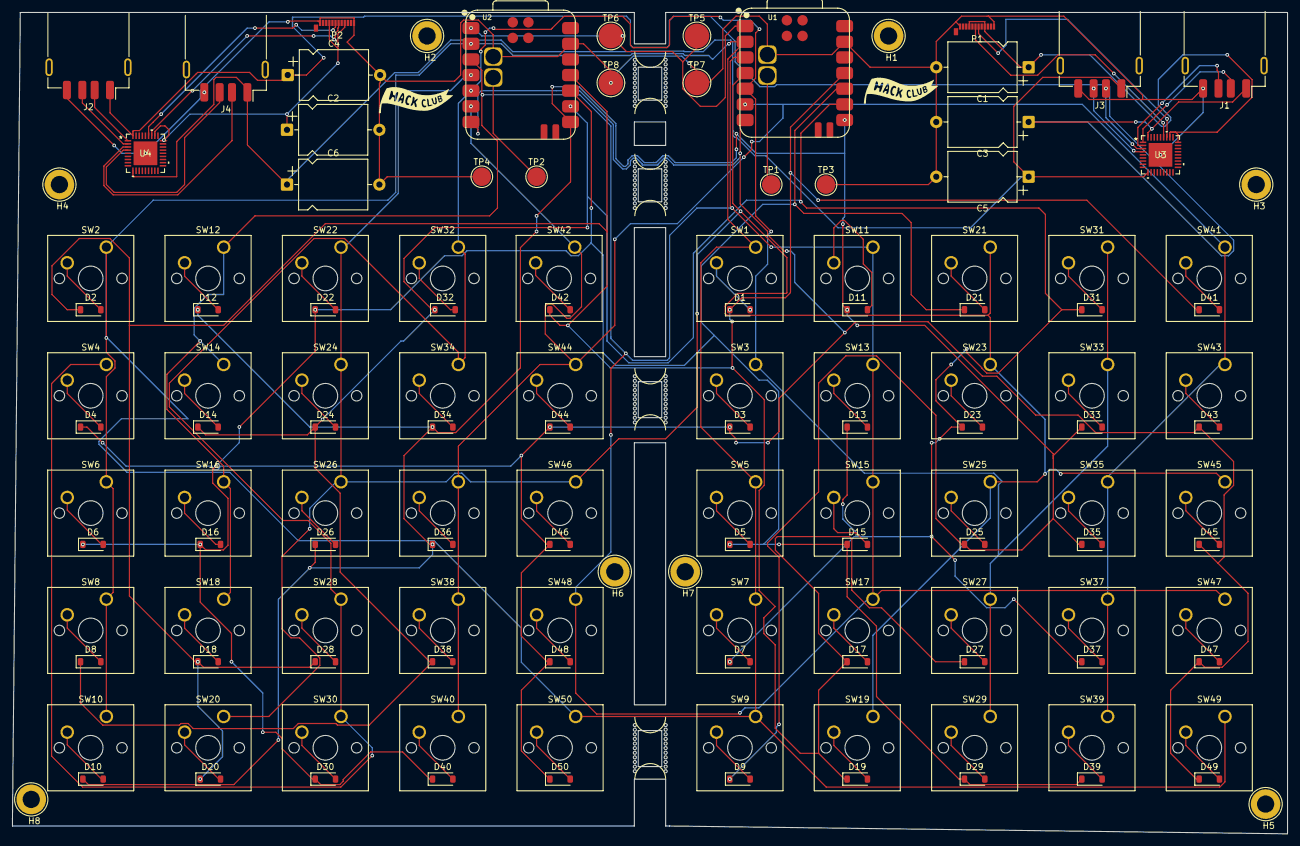
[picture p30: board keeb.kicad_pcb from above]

Board: 2 copper layers, 207.0 x 133.3 mm, 136 parts (0 on the bottom side), 80 nets.

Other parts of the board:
P2: USB_C; USB_C_Plug_Molex_105444
TP2: Batt+; TestPoint_Pad_D3.0mm
TP4: Batt-; TestPoint_Pad_D3.0mm
TP6: Motor+; TestPoint_Pad_D4.0mm
TP8: Motor-; TestPoint_Pad_D4.0mm

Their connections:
/right/vbat: TP2.1; also elsewhere on the board
GND: P2.A1 (GND), P2.A12 (GND), P2.B1 (GND), P2.B12 (GND), TP4.1, TP8.1; also elsewhere on the board
unnamed 63: P2.A6 (D+); also elsewhere on the board
unnamed 64: P2.A7 (D-); also elsewhere on the board
unnamed 66: P2.A4 (VBUS), P2.A9 (VBUS), P2.B4 (VBUS), P2.B9 (VBUS); also elsewhere on the board
data0: TP6.1; also elsewhere on the board

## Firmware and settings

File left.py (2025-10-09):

import board
import digitalio
import time
from adafruit_debouncer import Debouncer
import usb_hid
from adafruit_hid.keyboard import Keyboard
from adafruit_hid.keycode import Keycode
from adafruit_hid.consumer_control import ConsumerControl
from adafruit_hid.consumer_control_code import ConsumerControlCode
import neopixel

kbd = Keyboard(usb_hid.devices)
cc = ConsumerControl(usb_hid.devices)

#CODE FROM MY HACKPAD - REFERENCE

# pixel = neopixel.NeoPixel(board.NEOPIXEL, 1)
# pixel.brightness = 0.15

# layer_colors = [
#     (255, 0, 0),
#     (255, 80, 10),
#     (255, 255, 0),
#     (0, 255, 0),
#     (0, 0, 255),
#     (128, 0, 128),
#     (200, 70, 120),
#     (255, 255, 255)
# ]

# button_pins = [board.D8, board.D6, board.D10, board.D9, board.D5, board.D2, board.D1]
# layer_button_pin = board.D7

# buttons = []
# for pin in button_pins:
#     dio = digitalio.DigitalInOut(pin)
#     dio.direction = digitalio.Direction.INPUT
#     dio.pull = digitalio.Pull.UP
#     buttons.append(Debouncer(dio))

# layer_dio = digitalio.DigitalInOut(layer_button_pin)
# layer_dio.direction = digitalio.Direction.INPUT
# layer_dio.pull = digitalio.Pull.UP
# layer_button = Debouncer(layer_dio)

# # Layer definitions, labeled with their corresponding colors from layer_colors
# layers = [
#     # (255, 0, 0) - Red
#     [Keycode.A, Keycode.B, Keycode.C, Keycode.D, Keycode.E, Keycode.BACKSPACE, None],
#     # (255, 80, 10) - Orange
#     [Keycode.F, Keycode.G, Keycode.H, Keycode.I, Keycode.J, Keycode.LEFT_ARROW, Keycode.RIGHT_ARROW],
#     # (255, 255, 0) - Yellow
#     [Keycode.K, Keycode.L, Keycode.M, Keycode.N, Keycode.O, Keycode.UP_ARROW, Keycode.DOWN_ARROW],
#     # (0, 255, 0) - Green
#     [Keycode.P, Keycode.Q, Keycode.R, Keycode.S, Keycode.T, "VOLUME_DOWN", "VOLUME_UP"],
#     # (0, 0, 255) - Blue
#     [Keycode.U, Keycode.V, Keycode.W, Keycode.X, Keycode.Y, Keycode.PERIOD, Keycode.COMMA],
#     # (128, 0, 128) - Purple
#     [Keycode.Z, Keycode.ENTER, Keycode.SPACE, "CONTROL_TOGGLE", "SHIFT_TOGGLE", "QUESTION_MARK", Keycode.SEMICOLON],
#     # (200, 70, 120) - Pink
#     [Keycode.ONE, Keycode.TWO, Keycode.THREE, Keycode.FOUR, Keycode.FIVE, Keycode.TAB, Keycode.QUOTE],
#     # (255, 255, 255) - White
#     [Keycode.SIX, Keycode.SEVEN, Keycode.EIGHT, Keycode.NINE, Keycode.ZERO, Keycode.FORWARD_SLASH, Keycode.MINUS]
# ]

# layer = 0
# pixel[0] = layer_colors[layer]

# control_active = False
# shift_active = False

# while True:
#     for b in buttons:
#         b.update()
#     layer_button.update()

#     if layer_button.fell:
#         layer = (layer + 1) % len(layers)
#         print(f"Layer changed to {layer}")
#         pixel[0] = layer_colors[layer % len(layer_colors)]
        
#     for i, b in enumerate(buttons):
#         if b.fell:
#             key = layers[layer][i]
#             if key == "VOLUME_DOWN":
#                 cc.send(ConsumerControlCode.VOLUME_DECREMENT)
#                 print("Volume Down")
#             elif key == "VOLUME_UP":
#                 cc.send(ConsumerControlCode.VOLUME_INCREMENT)
#                 print("Volume Up")
#             elif key == "QUESTION_MARK":
#                 kbd.press(Keycode.SHIFT, Keycode.FORWARD_SLASH)
#                 kbd.release_all()
#                 print("Typed ?")
#             elif key == "CONTROL_TOGGLE":
#                 if control_active:
#                     kbd.release(Keycode.LEFT_CONTROL)
#                     control_active = False
#                     print("Control released")
#                 else:
#                     kbd.press(Keycode.LEFT_CONTROL)
#                     control_active = True
#                     print("Control pressed")
#             elif key == "SHIFT_TOGGLE":
#                 if shift_active:
#                     kbd.release(Keycode.LEFT_SHIFT)
#                     shift_active = False
#                     print("Shift released")
#                 else:
#                     kbd.press(Keycode.LEFT_SHIFT)
#                     shift_active = True
#                     print("Shift pressed")
#             else:
#                 print(f"Pressed key: {key}")
#                 # kbd.release(Keycode.LEFT_CONTROL)
#                 # control_active = False
#                 # print("Control released")
#                 # kbd.release(Keycode.LEFT_SHIFT)
#                 # shift_active = False
#                 # print("Shift released")
#                 if isinstance(key, int):
#                     kbd.press(key)

#         if b.rose:
#             key = layers[layer][i]
#             if isinstance(key, int):
#                 kbd.release(key)

#     time.sleep(0.01)


ROW_PINS = [board.D11, board.D10, board.D9, board.D8, board.D7]
COL_PINS = [board.D2, board.D3, board.D4, board.D5, board.D6]

rows = []
for pin in ROW_PINS:
    row = digitalio.DigitalInOut(pin)
    row.direction = digitalio.Direction.OUTPUT
    row.value = True
    rows.append(row)

cols = []
for pin in COL_PINS:
    col = digitalio.DigitalInOut(pin)
    col.direction = digitalio.Direction.INPUT
    col.pull = digitalio.Pull.UP
    cols.append(col)

#the thingies are out of order bc the rows and collums are not in order on the pcb, row 3 might be before row 2 on col 4, so this is js a hard map that should compensate so I dont have to reroute

matrix_layers = [
    #   0        1         2          3         4
    [Keycode.1, Keycode.X, Keycode.LEFT_SHIFT, Keycode.C, Keycode.5]#0
    [Keycode.A, Keycode.S, Keycode.3, Keycode.WINDOWS, Keycode.SPACE],#1
    [Keycode.Z, Keycode.W, Keycode.E, Keycode.4, Keycode.V],#2
    [Keycode.LEFT_CONTROL, Keycode.2, Keycode.D, Keycode.R, Keycode.F],#3
    [Keycode.SPACE, Keycode.B, Keycode.G, Keycode.Q, Keycode.T],#4
]

matrix_layer = 0
matrix_state = [[False for _ in COL_PINS] for _ in ROW_PINS]

while True:
    for row_idx, row in enumerate(rows):
        row.value = False
        for col_idx, col in enumerate(cols):
            pressed = not col.value
            prev = matrix_state[row_idx][col_idx]
            key = matrix_layers[row_idx][col_idx]
            if pressed and not prev:
                if key is not None:
                    if isinstance(key, int):
                        kbd.press(key)
                        print(f"Matrix pressed: {key}")
                        d0 = digitalio.DigitalInOut(board.D0)
                        d0.direction = digitalio.Direction.OUTPUT
                        d0.value = True
                        time.sleep(0.01)
                        d0.value = False
                        d0.deinit()
            elif not pressed and prev:
                if key is not None and isinstance(key, int):
                    kbd.release(key)
                    print(f"Matrix released: {key}")
            matrix_state[row_idx][col_idx] = pressed
        row.value = True
    time.sleep(0.001)

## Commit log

2025-10-04 finished the schematic
    [CON_2082940020.step, CON_2082940030.step, CON_2082940040.step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]
2025-10-04 assigned footprints, fixed electrical rules checker errors
    I fixed the ERC errors by adding no connect flags to the unused pins, I assigned the footprints for all the components, and initialized the PCB with all the components. I also forgot to add the mounting holes and mousebites to the last commit, so I added those as well. Next commit will be routing all the components, then full CAD, then firmware (looking to use KMK as that's what I used for the Macropad)
    [keeb.kicad_pcb, side.kicad_sch]
2025-10-04 worked on routing
    [keeb.kicad_pcb]
2025-10-05 finished routing, added the back Silkscreen, fixed DRC
    I finished the leftover routing, added some images to the back silkscreen, and went through the DRC errors. There are still some problems with the USB-C port's clearance, but otherwise, the PCB is almost done. I'll try to get the Cad and FW done this week so I can wrap up and submit on Sat. PCB way says ~54$ for the pcb.
    [keeb-B_Cu.gbr, keeb-B_Mask.gbr, keeb-B_Paste.gbr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]
2025-10-07 fixed some pcbway errors
    [keeb-B_Cu.gbr, keeb-B_Mask.gbr, keeb-B_Paste.gbr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]
2025-10-08 cad stuff
    [0.3mf, 0_F10.3mf, 1.25U_Command.3mf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]
2025-10-09 wrapped up project and made the BOM
    [BOM.csv]
2025-10-09 bom has to be lowercase lmao
    [bom.csv]
